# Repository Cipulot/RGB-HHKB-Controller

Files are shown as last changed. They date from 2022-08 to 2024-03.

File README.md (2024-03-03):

# RGB HHKB Controller

 HHKB Pro 2 Keyboard Controller Board with RGB strip support.

## Introduction

This project is a continuation of my development of open source EC boards.

It's a derivative of the [Hasu HHKB Controller](https://github.com/tmk/HHKB_controller) with an updated MCU package and RGB strip support.

This board is USB-mode only and is **NOT** compatible with the BLE options.

## Technical information

- Microcontroller: Atmel Atmega32U4
- Connector:
  - USB-C
  - HHKB ANSI connector
  - HHKB JP connector
- Firmware compatibility: QMK (with VIA/VIAL support)
- Protection hardware (on all connection methods):
  - Fused
  - ESD protection
-RGB strip connector, both THT and SMD pad on both sides of the board.

## Renders and Prototypes

### Render

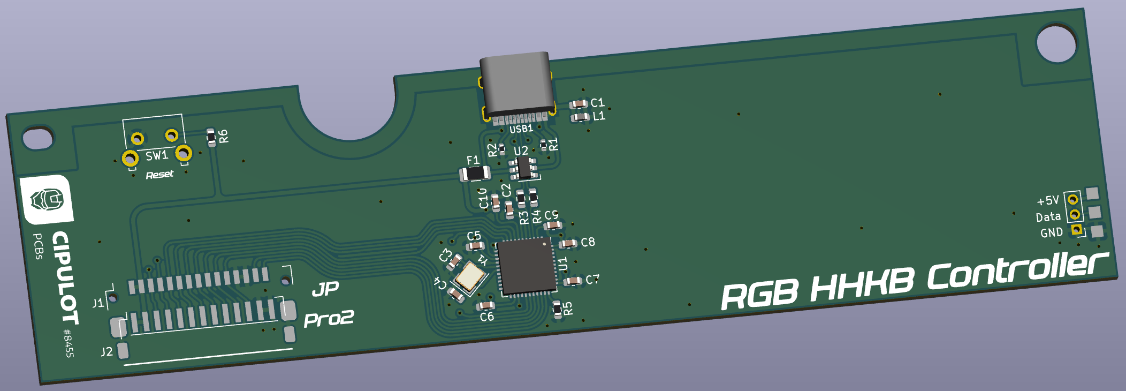
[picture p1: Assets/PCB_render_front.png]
PCB Front Render


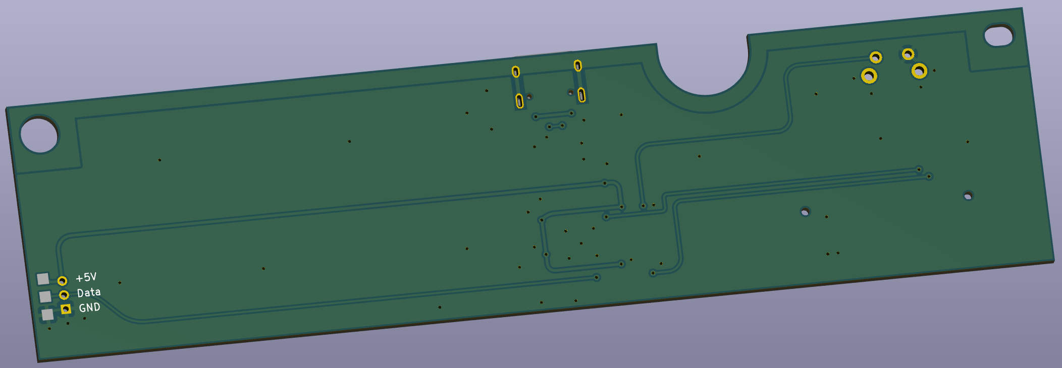
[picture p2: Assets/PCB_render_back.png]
PCB Back Render


### Prototype

TBD

## Revisions and relative features

### Rev1

This revision implements all the main features of the PCB.

The controller is electrically compatible with both the ANSI and JP version of the HHKB keyboard but you will need to chose between the 2 connectors.

#### Connector choice

Pay attention at the time or ordering the PCBs to populate only one of the 2 connectors:

- `S13B-ZR-SM4A-TF` for ANSI
- `DF14A-15P-1.25H` for JP

## License

<br />This work is licensed under a <a rel="license" href="http://creativecommons.org/licenses/by-nc-sa/4.0/">Creative Commons Attribution-NonCommercial-ShareAlike 4.0 International License</a>.

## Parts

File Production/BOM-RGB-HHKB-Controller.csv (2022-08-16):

Comment | Designator | Footprint | LCSC | MPN
ATmega32U4-M | U1 | QFN-44-1EP_7x7mm_P0.5mm_EP5.2x5.2mm | C112161
16MHz | Y1 | Crystal_SMD_3225-4pin_3.2x2.5mm | C13738
100n | C1,C5,C6,C7,C8,C9 | C_0603_1608Metric | C14663
1u | C2 | C_0603_1608Metric | C15849
22p | C3,C4 | C_0603_1608Metric | C1653
HRO-TYPE-C-31-M-12 | USB1 | HRO-TYPE-C-31-M-12-Assembly | C165948
22 | R3,R4 | R_0603_1608Metric | C23345
10k | R5,R6 | R_0603_1608Metric | C25804
5.1k | R1,R2 | R_0402_1005Metric | C25905
SW_Push | SW1 | SW_Tactile_SKHH_Angled | C318884
500mA | F1 | Fuse_1206_3216Metric | C70076
SRV05-4 | U2 | SOT-23-6-routable | C85364
220 @ 100MHz, 2A | L1 | L_0603_1608Metric | C85832
10u | C10 | C_0603_1608Metric | C96446
Conn_01x15 | J1 | DF14A-15P-1.25H | DF14A-15P-1.25H | DF14A-15P-1.25H
Conn_01x13 | J2 | S13B-ZR-SM4A-TF | S13B-ZR-SM4A-TF(LF)(SN) | S13B-ZR-SM4A-TF(LF)(SN)

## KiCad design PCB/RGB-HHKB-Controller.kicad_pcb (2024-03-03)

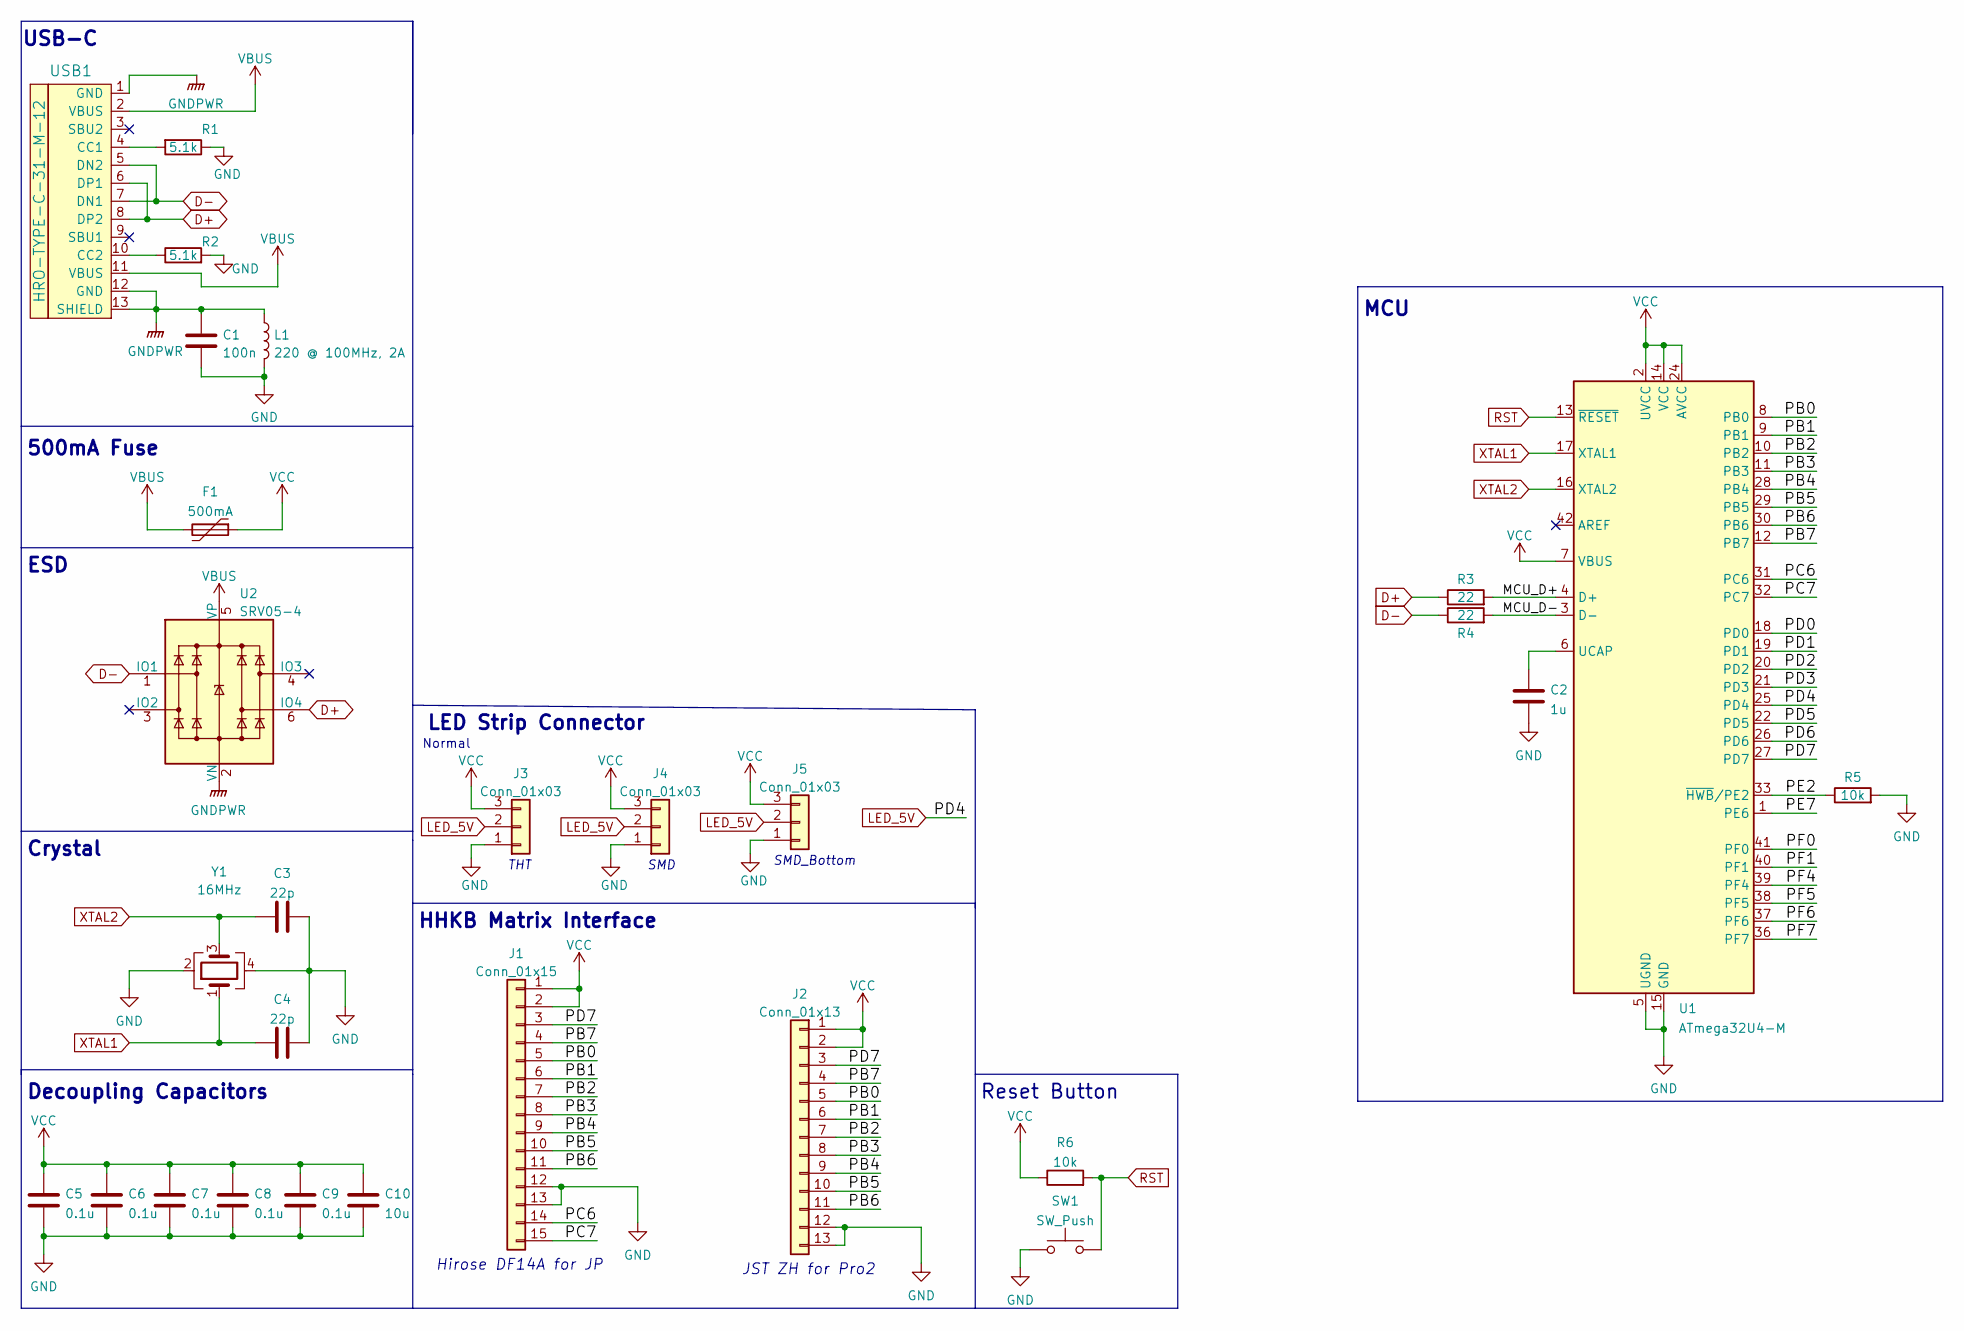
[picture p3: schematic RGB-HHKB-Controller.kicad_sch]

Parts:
C1: 100n; C_0603_1608Metric; LCSC C14663
C2: 1u; C_0603_1608Metric; LCSC C15849
C3, C4: 22p; C_0603_1608Metric; LCSC C1653
C5, C6, C7, C8, C9: 0.1u; C_0603_1608Metric; LCSC C14663
C10: 10u; C_0603_1608Metric; LCSC C96446
F1: 500mA; Fuse_1206_3216Metric; LCSC C70076
J1: Conn_01x15; DF14A-15P-1.25H
J2: Conn_01x13; S13B-ZR-SM4A-TF
J3: Conn_01x03; PinHeader_1x03_P2.00mm_Vertical
J4, J5: Conn_01x03; LED_Strip_Pad
L1: 220 @ 100MHz, 2A; L_0603_1608Metric; LCSC C85832
R1, R2: 5.1k; R_0402_1005Metric; LCSC C25905
R3, R4: 22; R_0603_1608Metric; LCSC C23345
R5: 10k; R_0603_1608Metric
R6: 10k; R_0603_1608Metric; LCSC C25804
SW1: SW_Push; SW_Tactile_SKHH_Angled; LCSC C139763
U1: ATmega32U4-M; QFN-44-1EP_7x7mm_P0.5mm_EP5.2x5.2mm; LCSC C112161
U2: SRV05-4; SOT-23-6-routable; LCSC C85364
USB1: HRO-TYPE-C-31-M-12; HRO-TYPE-C-31-M-12-Assembly; LCSC C165948
Y1: 16MHz; Crystal_SMD_3225-4pin_3.2x2.5mm; LCSC C13738

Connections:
/MCU_D+: R3.2, U1.4 (D+)
/MCU_D-: R4.2, U1.3 (D-)
/PB0: J1.5, J2.5, U1.8 (PB0)
/PB1: J1.6, J2.6, U1.9 (PB1)
/PB2: J1.7, J2.7, U1.10 (PB2)
/PB3: J1.8, J2.8, U1.11 (PB3)
/PB4: J1.9, J2.9, U1.28 (PB4)
/PB5: J1.10, J2.10, U1.29 (PB5)
/PB6: J1.11, J2.11, U1.30 (PB6)
/PB7: J1.4, J2.4, U1.12 (PB7)
/PC6: J1.14, U1.31 (PC6)
/PC7: J1.15, U1.32 (PC7)
/PD0: U1.18 (PD0)
/PD1: U1.19 (PD1)
/PD2: U1.20 (PD2)
/PD3: U1.21 (PD3)
/PD5: U1.22 (PD5)
/PD6: U1.26 (PD6)
/PD7: J1.3, J2.3, U1.27 (PD7)
/PE2: R5.1, U1.33 (~HWB/PE2)
/PE7: U1.1 (PE6)
/PF0: U1.41 (PF0)
/PF1: U1.40 (PF1)
/PF4: U1.39 (PF4)
/PF5: U1.38 (PF5)
/PF6: U1.37 (PF6)
/PF7: U1.36 (PF7)
D+: R3.1, U2.6 (IO4), USB1.6 (DP1), USB1.8 (DP2)
D-: R4.1, U2.1 (IO1), USB1.5 (DN2), USB1.7 (DN1)
GND: C1.2, C2.2, C3.1, C4.1, C5.2, C6.2, C7.2, C8.2, C9.2, C10.2, J1.12, J1.13, J2.12, J2.13, J3.1, J4.1, J5.1, L1.2, R1.1, R2.2, R5.2, SW1.1, U1.5 (UGND), U1.15 (GND), U1.23 (GND), U1.35 (GND), U1.43 (GND), U1.45 (GND), Y1.2, Y1.4
GNDPWR: C1.1, L1.1, U2.2 (VN), USB1.1 (GND), USB1.12 (GND), USB1.13 (SHIELD)
LED_5V: J3.2, J4.2, J5.2, U1.25 (PD4)
unnamed: C2.1, U1.6 (UCAP)
unnamed: R1.2, USB1.4 (CC1)
unnamed: R2.1, USB1.10 (CC2)
RST: R6.2, SW1.2, U1.13 (~RESET)
VBUS: F1.2, U2.5 (VP), USB1.2 (VBUS), USB1.11 (VBUS)
VCC: C5.1, C6.1, C7.1, C8.1, C9.1, C10.1, F1.1, J1.1, J1.2, J2.1, J2.2, J3.3, J4.3, J5.3, R6.1, U1.2 (UVCC), U1.7 (VBUS), U1.14 (VCC), U1.24 (AVCC), U1.34 (VCC), U1.44 (AVCC)
XTAL1: C4.2, U1.17 (XTAL1), Y1.1
XTAL2: C3.2, U1.16 (XTAL2), Y1.3

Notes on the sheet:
LED Strip Connector
SMD_Bottom
JST ZH for Pro2
Crystal
SMD
500mA Fuse
Hirose DF14A for JP
Decoupling Capacitors
MCU
USB-C
Reset Button
ESD
THT
HHKB Matrix Interface
Normal

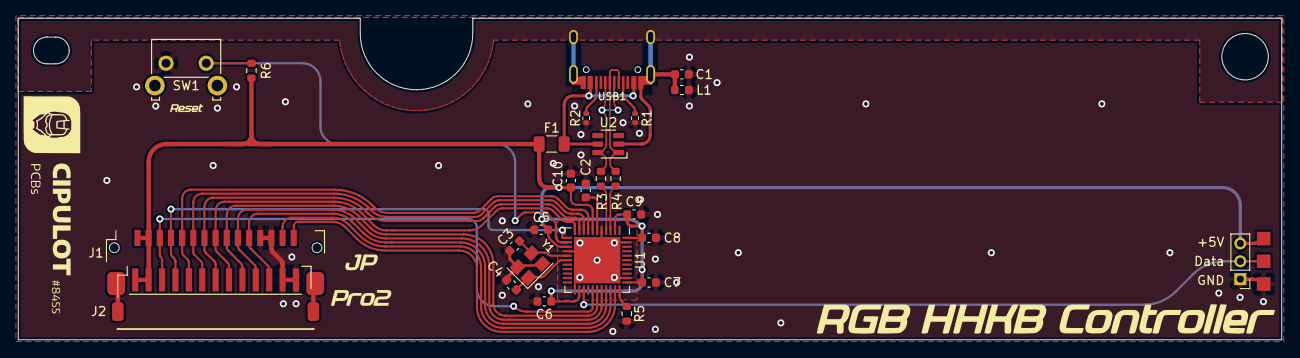
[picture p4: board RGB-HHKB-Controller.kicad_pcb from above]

Board: 2 copper layers, 141.5 x 36.0 mm, 28 parts (0 on the bottom side), 27 nets.

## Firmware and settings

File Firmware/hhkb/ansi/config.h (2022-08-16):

/*
Copyright 2022 Cipulot

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
You should have received a copy of the GNU General Public License
along with this program.  If not, see <http://www.gnu.org/licenses/>.
*/

#pragma once

#include "config_common.h"

/* key matrix size */
#define MATRIX_ROWS 8
#define MATRIX_COLS 8

#define TAPPING_TERM 200

/* number of backlight levels */
#define BACKLIGHT_LEVELS 3

/* Set 0 if debouncing isn't needed */
#define DEBOUNCE 5

#ifdef HHKB_RN42_ENABLE
// rn42 support -- acquired from the tmk repo. This is almost certainly not
// integrated with qmk in the correct way.

#    define SUART_OUT_PORT PORTD
#    define SUART_OUT_BIT 0
#    define SUART_IN_PIN PIND
#    define SUART_IN_BIT 1

#    define SERIAL_UART_BAUD 115200
#    define SERIAL_UART_INIT_CUSTOM                 \
        /* RX interrupt, RX: enable */              \
        UCSR1B |= (1 << RXCIE1) | (1 << RXEN1);     \
        /* TX interrupt, TX: enable */              \
        UCSR1B |= (0 << TXCIE1) | (1 << TXEN1);     \
        /* parity: none(00), even(01), odd(11) */   \
        UCSR1C |= (0 << UPM11) | (0 << UPM10);      \
        /* RTS, CTS(no flow control by hardware) */ \
        UCSR1D |= (0 << RTSEN) | (0 << CTSEN);      \
        /* RTS for flow control by firmware */      \
        DDRD |= (1 << 5);                           \
        PORTD &= ~(1 << 5);
#    define SERIAL_UART_RTS_LO() \
        do {                     \
            PORTD &= ~(1 << 5);  \
        } while (0)
#    define SERIAL_UART_RTS_HI() \
        do {                     \
            PORTD |= (1 << 5);   \
        } while (0)

/* power control of key switch board */
#    define HHKB_POWER_SAVING

#endif

/*
 * Feature disable options
 *  These options are also useful to firmware size reduction.
 */

/* disable debug print */
//#define NO_DEBUG

/* disable print */
//#define NO_PRINT

/* disable action features */
//#define NO_ACTION_LAYER
//#define NO_ACTION_TAPPING
//#define NO_ACTION_ONESHOT

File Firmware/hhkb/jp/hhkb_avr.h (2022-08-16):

/*
Copyright 2022 Cipulot

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
You should have received a copy of the GNU General Public License
along with this program.  If not, see <http://www.gnu.org/licenses/>.
*/

#pragma once

#include <stdint.h>
#include <stdbool.h>
#include <avr/io.h>
#include <avr/interrupt.h>
#include <util/delay.h>

// Timer resolution check
#if (1000000 / TIMER_RAW_FREQ > 20)
#    error "Timer resolution(>20us) is not enough for HHKB matrix scan tweak on V-USB."
#endif

/*
 * HHKB Matrix I/O
 *
 * row:     HC4051[A,B,C]  selects scan row0-7
 * row-ext: [En0,En1] row extention for JP
 * col:     LS145[A,B,C,D] selects scan col0-7 and enable(D)
 * key:     on: 0/off: 1
 * prev:    hysteresis control: assert(1) when previous key state is on
 */

#if defined(__AVR_ATmega32U4__)
/*
 * For TMK HHKB alt controller(ATMega32U4)
 *
 * row:     PB0-2
 * col:     PB3-5,6
 * key:     PD7(pull-uped)
 * prev:    PB7
 * power:   PD4(L:off/H:on)
 * row-ext: PC6,7 for HHKB JP(active low)
 */
static inline void KEY_ENABLE(void) {
    (PORTB &= ~(1 << 6));
}
static inline void KEY_UNABLE(void) {
    (PORTB |= (1 << 6));
}
static inline bool KEY_STATE(void) {
    return (PIND & (1 << 7));
}
static inline void KEY_PREV_ON(void) {
    (PORTB |= (1 << 7));
}
static inline void KEY_PREV_OFF(void) {
    (PORTB &= ~(1 << 7));
}
#    ifdef HHKB_POWER_SAVING
static inline void KEY_POWER_ON(void) {
    DDRB  = 0xFF;
    PORTB = 0x40; // change pins output
    DDRD |= (1 << 4);
    PORTD |= (1 << 4); // MOS FET switch on
    /* Without this wait you will miss or get false key events. */
    _delay_ms(5); // wait for powering up
}
static inline void KEY_POWER_OFF(void) {
    /* input with pull-up consumes less than without it when pin is open. */
    DDRB  = 0x00;
    PORTB = 0xFF; // change pins input with pull-up
    DDRD |= (1 << 4);
    PORTD &= ~(1 << 4); // MOS FET switch off
}
static inline bool KEY_POWER_STATE(void) {
    return PORTD & (1 << 4);
}
#    else
static inline void KEY_POWER_ON(void) {}
static inline void KEY_POWER_OFF(void) {}
static inline bool KEY_POWER_STATE(void) {
    return true;
}
#    endif
static inline void KEY_INIT(void) {
    /* row,col,prev: output */
    DDRB  = 0xFF;
    PORTB = 0x40; // unable
    /* key: input with pull-up */
    DDRD &= ~0x80;
    PORTD |= 0x80;

    /* row extention for HHKB JP */
    DDRC |= (1 << 6 | 1 << 7);
    PORTC |= (1 << 6 | 1 << 7);

    KEY_UNABLE();
    KEY_PREV_OFF();

    KEY_POWER_OFF();
}
static inline void KEY_SELECT(uint8_t ROW, uint8_t COL) {
    PORTB = (PORTB & 0xC0) | (((COL)&0x07) << 3) | ((ROW)&0x07);

    if ((ROW)&0x08)
        PORTC = (PORTC & ~(1 << 6 | 1 << 7)) | (1 << 6);
    else
        PORTC = (PORTC & ~(1 << 6 | 1 << 7)) | (1 << 7);
}

#elif defined(__AVR_AT90USB1286__)
/*
 * For Teensy++(AT90USB1286)
 *
 *                          HHKB pro    HHKB pro2
 * row:     PB0-2           (6-8)       (5-7)
 * col:     PB3-5,6         (9-12)      (8-11)
 * key:     PE6(pull-uped)  (4)         (3)
 * prev:    PE7             (5)         (4)
 *
 * TODO: convert into 'staitc inline' function
 */
#    define KEY_INIT()         \
        do {                   \
            DDRB |= 0x7F;      \
            DDRE |= (1 << 7);  \
            DDRE &= ~(1 << 6); \
            PORTE |= (1 << 6); \
        } while (0)
#    define KEY_SELECT(ROW, COL) (PORTB = (PORTB & 0xC0) | (((COL)&0x07) << 3) | ((ROW)&0x07))
#    define KEY_ENABLE() (PORTB &= ~(1 << 6))
#    define KEY_UNABLE() (PORTB |= (1 << 6))
#    define KEY_STATE() (PINE & (1 << 6))
#    define KEY_PREV_ON() (PORTE |= (1 << 7))
#    define KEY_PREV_OFF() (PORTE &= ~(1 << 7))
#    define KEY_POWER_ON()
#    define KEY_POWER_OFF()
#    define KEY_POWER_STATE() true

#else
#    error "define code for matrix scan"
#endif

#if 0
// For ATMega328P with V-USB
//
// #elif defined(__AVR_ATmega328P__)
// Ports for V-USB
// key:     PB0(pull-uped)
// prev:    PB1
// row:     PB2-4
// col:     PC0-2,3
// power:   PB5(Low:on/Hi-z:off)
#    define KEY_INIT()         \
        do {                   \
            DDRB |= 0x3E;      \
            DDRB &= ~(1 << 0); \
            PORTB |= 1 << 0;   \
            DDRC |= 0x0F;      \
            KEY_UNABLE();      \
            KEY_PREV_OFF();    \
        } while (0)
#    define KEY_SELECT(ROW, COL)                        \
        do {                                            \
            PORTB = (PORTB & 0xE3) | ((ROW)&0x07) << 2; \
            PORTC = (PORTC & 0xF8) | ((COL)&0x07);      \
        } while (0)
#    define KEY_ENABLE() (PORTC &= ~(1 << 3))
#    define KEY_UNABLE() (PORTC |= (1 << 3))
#    define KEY_STATE() (PINB & (1 << 0))
#    define KEY_PREV_ON() (PORTB |= (1 << 1))
#    define KEY_PREV_OFF() (PORTB &= ~(1 << 1))
// Power supply switching
#    define KEY_POWER_ON()      \
        do {                    \
            KEY_INIT();         \
            PORTB &= ~(1 << 5); \
            _delay_ms(1);       \
        } while (0)
#    define KEY_POWER_OFF() \
        do {                \
            DDRB &= ~0x3F;  \
            PORTB &= ~0x3F; \
            DDRC &= ~0x0F;  \
            PORTC &= ~0x0F; \
        } while (0)
#endif

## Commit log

2022-08-16 PCB project init
    [RGB-HHKB-Controller.kicad_pcb, RGB-HHKB-Controller.kicad_sch, bluetooth.kicad_sch]
2022-08-16 Production files init
    [BOM-RGB-HHKB-Controller.csv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]
2024-03-03 Updated the License for the project and relative details.
    [RGB-HHKB-Controller.kicad_pcb, RGB-HHKB-Controller.kicad_sch]

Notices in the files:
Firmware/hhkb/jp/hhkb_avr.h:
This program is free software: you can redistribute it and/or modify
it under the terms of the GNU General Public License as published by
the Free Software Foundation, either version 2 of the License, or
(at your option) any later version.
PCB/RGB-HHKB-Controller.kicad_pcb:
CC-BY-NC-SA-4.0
